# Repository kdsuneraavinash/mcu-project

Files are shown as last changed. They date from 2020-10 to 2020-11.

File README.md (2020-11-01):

# Environment Monitoring IoT Device with Common Alert Protocol

> A device developed using the NodeMCU ESP32S micro-controller, which monitors environment parameters such as temperature, humidity, barometric pres-sure, and ambient light level. 

For a more detailed report see [HERE](Report/report.pdf)

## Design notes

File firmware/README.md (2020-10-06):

# Microcontroller Module Project

> Developed using NODEMCU-ESP32S using PlatformIo.

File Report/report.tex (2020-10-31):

\documentclass[12pt,a4paper]{article}

\usepackage[left=1in,top=1in,right=1in,bottom=1in]{geometry}
\usepackage[T1]{fontenc}
\usepackage[utf8]{inputenc}
\usepackage{minted}

\usepackage{courier}
\usepackage{indentfirst}
\usepackage{graphicx}
\usepackage[hidelinks]{hyperref}
\usepackage{tikz}
\usepackage{array}
\usepackage{tabularx}
\usepackage{enumitem}
\usepackage[ruled,vlined]{algorithm2e}
\SetAlFnt{\footnotesize}

\newcommand{\tab}[1]{\hspace*{25pt}}

\def\sectionskip{\medskip}
\def\sectionlineskip{\medskip}
\urlstyle{same}

\title{Title of Document}
\author{K. D. Sunera Avinash Chandrasiri (170081L)}

\begin{document}

% ======================================
% Cover Page
% ======================================

\begin{titlepage}
    \begin{tikzpicture}[overlay,remember picture]
    \end{tikzpicture}

    {\hfill\scshape\Large Final Report \par}
    {\hfill\scshape CS3242 Micro-controllers and Applications\par}
    {\vspace{.5cm}}
    {\hrule}
    \vspace{2.5cm}
    {\hfill\huge\bfseries Environment Monitoring IoT Device\par}
    {\hfill\huge\bfseries with Common Alert Protocol\par}
    \vspace{1cm}
    {\hfill\large K. D. Sunera Avinash Chandrasiri\par}
    {\hfill\large 170081L\par}
    \vfill
    \hfill \today \par
\end{titlepage}

\newpage

% ======================================
% Table of Contents
% ======================================

\tableofcontents
\newpage

% ======================================
% Scope of the project
% ======================================

\section{Introduction}

\subsection{Scope}

This project is a device developed using the
\textbf{NodeMCU 32S} micro-controller, which monitors
environment parameters such as \textbf{temperature,
    humidity, barometric pressure, and ambient
    light level}. The used micro-controller will
operate with low-power and via a wi-fi connection.
Even though the wi-fi connection network
availability may be unreliable, firmware
for the microcontroller is designed in a way
so that network unreliability would not
entirely hinder the operation of the sensor. \par

The device will connect with a remote server via
an HTTP request. Here the microcontroller will
use \textbf{CAP(Common Alert Protocol)} to deliver the
relevant parameters. This "server sync" will
happen once every 15 minutes. In these situations,
the device will send the mean and the standard
deviation of the samples the device collected
within that 15 minutes.  If the network connection
fails for some reason, the device would still cache
the requests(up to a certain extent) and resend/replay
those messages once the network reconnects. \par

The backend implemented for the project is a simple
server based off of python. It uses \textbf{flask}
framework and sqlite database. It simply accepts alert
notifications sent by the device and displays them
in a tabular manner. \par

\subsection{Features}

Following are some of the features available in the device.
Node that following list also includes the features that were
expected from the project as well as some special features.
\setlist{nolistsep}
\begin{itemize}[noitemsep]
    \item Measuring temperature, humidity, barometric pressure, and ambient light level.
    \item Syncing with the server every 15 minutes.
    \item Use Common Alert Protocol 1.2 to deliver the messages.
    \item Replay messages that failed to deliver to the server due to network issues.
    \item In case of replaying past messages, timestamp is also sent after retreiveing it via NTP, so the server can correctly order the messages.
    \item Create a unique session identifier at the initialization of the device.
    \item Support multi-device connections. Because of the above unique identifier, we can connect multiple devices to the server.
\end{itemize}

\newpage

\section{Design}

% ======================================
% Diagram to explain high-level design
% ======================================

\subsection{High Level Design}

Following the high level system diagram is shown.
The system will mainly consist of two major parts; embedded device and the remote server.
The device will use a Wi-Fi connection to connect to the remote server.

\begin{figure}[h]
    \centering
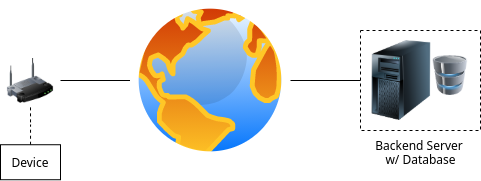
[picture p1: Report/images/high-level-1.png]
    
    \caption{High Level Deployment Diagram}
\end{figure}

The high-level diagram of the embedded device is shown below.
Here, the sensors required are connected; BMP180 (for pressure sensing),
DHT11 (for humidity and temperature sensing) and LDR(for light level sensing).

\begin{figure}[h]
    \centering
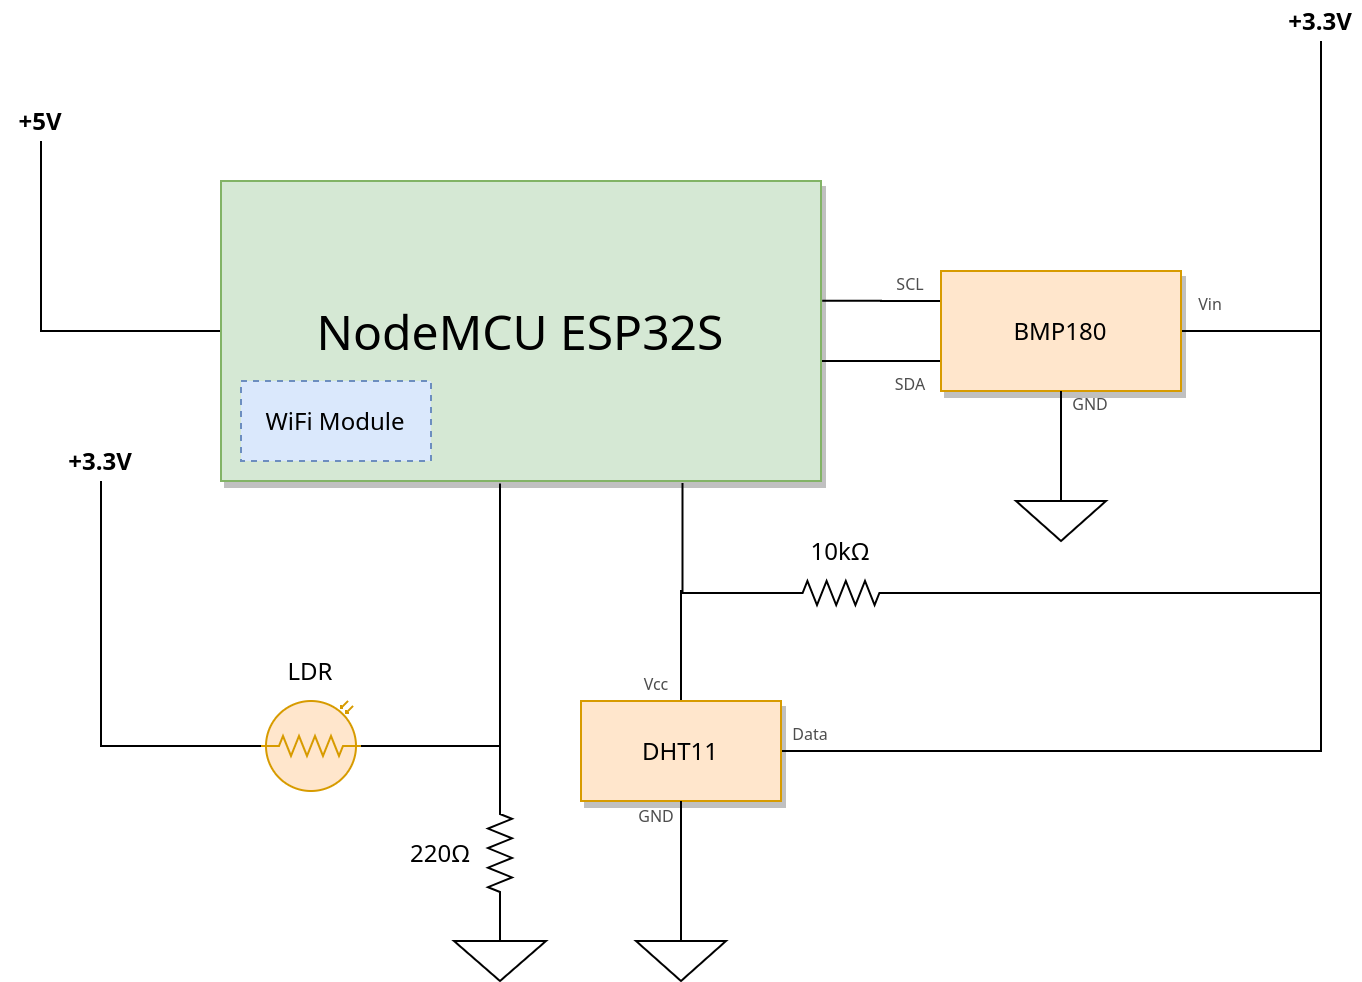
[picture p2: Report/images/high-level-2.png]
    
    \caption{High Level Device Diagram}
\end{figure}

\noindent The device will run on 5V input voltage while the input/output high
voltage of the NodeMCU will be 3.3V.

\clearpage

\newpage

% ======================================
%  List of components and their cost
% ======================================

\subsection{Components and Cost Breakdown}

\begin{figure}[!htb]
    \minipage{0.25\textwidth}
    \centering
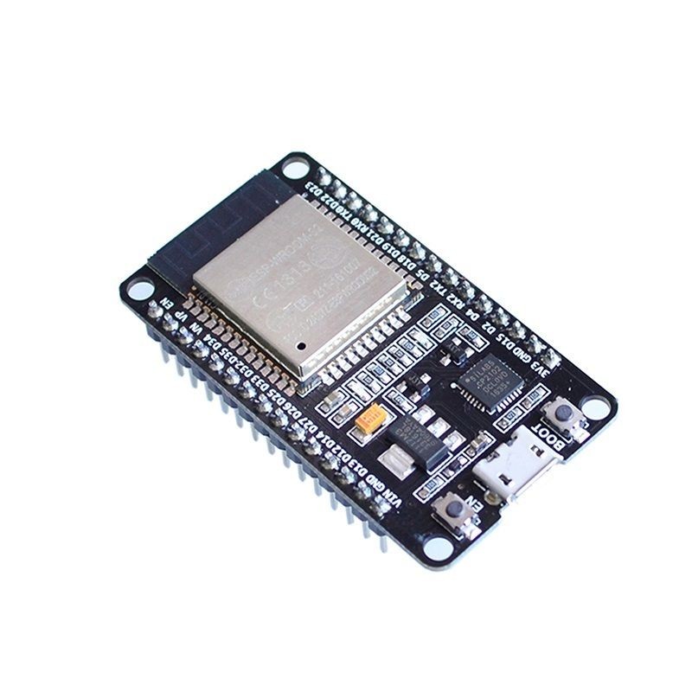
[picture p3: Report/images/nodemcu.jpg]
    
    \endminipage\hfill
    \minipage{0.25\textwidth}
    \centering
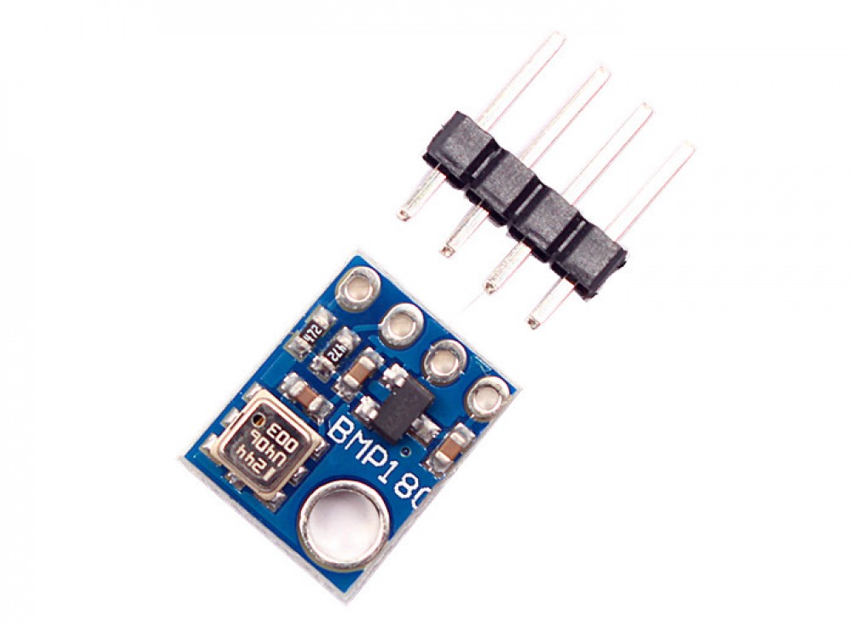
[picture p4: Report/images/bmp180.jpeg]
    
    \endminipage\hfill
    \minipage{0.25\textwidth}
    \centering
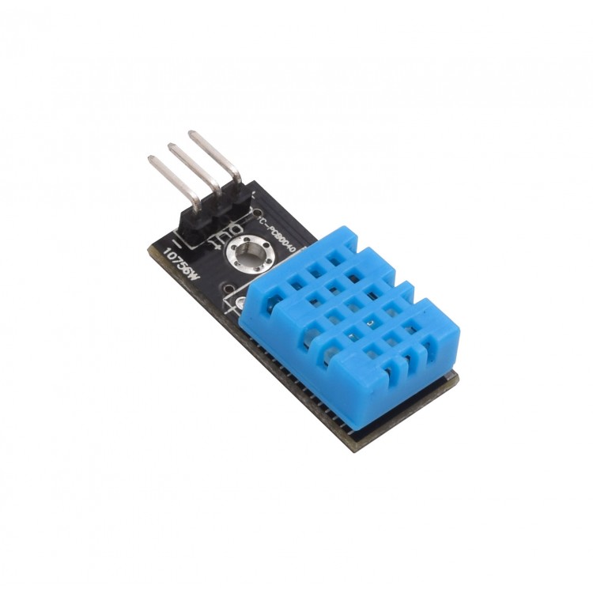
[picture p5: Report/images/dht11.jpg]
    
    \endminipage\hfill
    \minipage{0.25\textwidth}%
    \centering
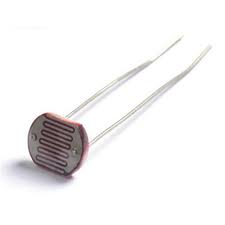
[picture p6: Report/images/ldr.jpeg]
    
    \endminipage
    \caption{From left to right - NodeMCU, BMP180, DHT11, LDR}
\end{figure}

The Price Breakdown for the product components are given below.
The chosen micro-controller board was \textbf{NodeMCU ESP-32S IoT Dev Board}
mainly because of its inbuilt Wi-Fi capabilities and its specialization
on such tasks, especially on IoT field.
Apart form that, for the sensors, following sensors were chosen. \par

\begin{figure}[h]
    \begin{tabular}{lp{11.5cm}}
        \textbf{DHT11 Sensor}  & Temperature and Relative Humidity Sensor Module. Temperature range is 0°C to 50°C (±1°C) and Humidity Range is 20\% to 90\% (±1\%) Operating voltage is  3.5V to 5.5V. \\
        \textbf{BMP180 Sensor} & Barometric Pressure sensor module. Range is 300hPa to 1100 hPa with 0.02 hPa accuracy. Operating voltage is 1.8-6 V.                                                   \\
        \textbf{LDR}           & Light Dependent Resistor for measuring ambient light level.                                                                                                            \\
    \end{tabular}
    \label{fig:layers}
\end{figure}

\noindent Cost breakdown for the device excluding connectors, resistors, bread-boards, etc... is given below.

\vspace{3mm}

\noindent\begin{tabularx}{\linewidth}{|X|r|}
    \hline
    \bf Component Name                                          & \bf Subtotal (LKR) \\
    \hline
    \hline
    NodeMCU ESP-32S WiFi Bluetooth Dual Mode IoT Dev Board      & 1050.00            \\
    BMP180 Barometric Pressure, Temperature and Altitude Sensor & 185.00             \\
    DHT11 Temperature and Relative Humidity Sensor Module       & 250.00             \\
    LDR 4mm                                                     & 10.00              \\
    \hline
    \hline
    \bf  Total Amount (LKR)                                     & \bf 1495.00        \\
    \hline
\end{tabularx}

\vspace{3mm}

The cost could have been further reduced by using a \textbf{NodeMCU ESP-8266} board.
This costs about half of the NodeMCU ESP-32S price.
However, ESP-32S was cited as being more reliable than ESP-8266.
So, ESP-32S was used.

\newpage

% ======================================
% Schematic diagram giving all components
% ======================================

\subsection{Schematic Diagram}

\vspace{2cm}

\begin{figure}[h]
    \centering
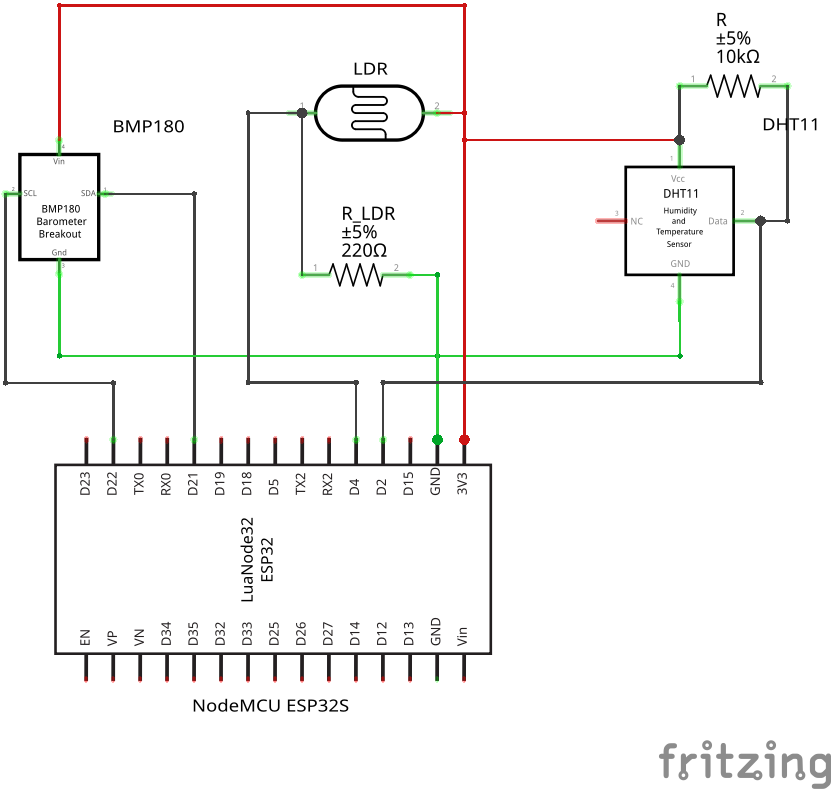
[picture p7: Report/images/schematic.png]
    
    \caption{Schematic Diagram of the device}
\end{figure}

\begin{figure}[H]
    \centering
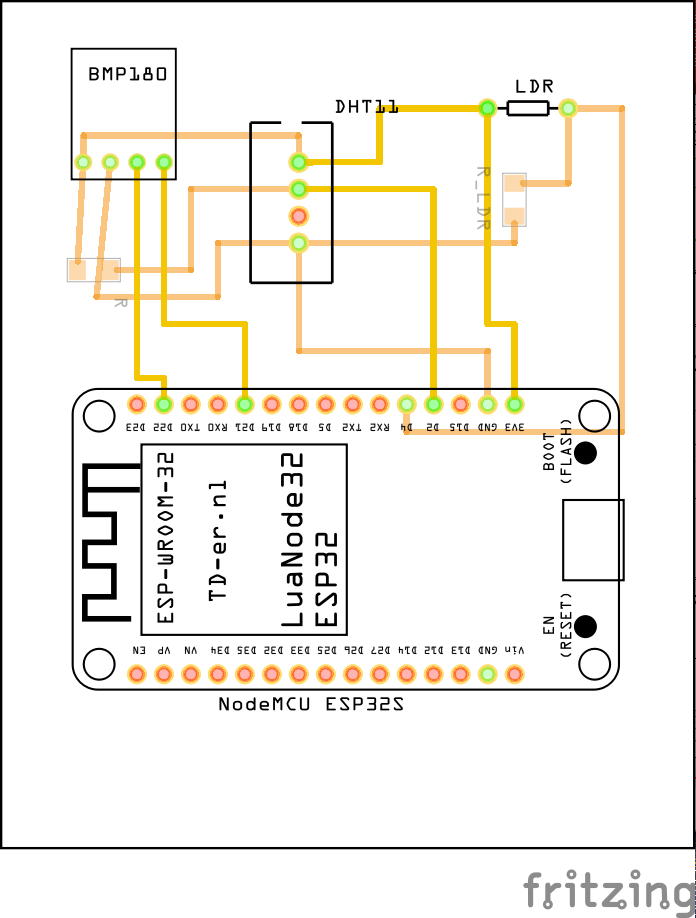
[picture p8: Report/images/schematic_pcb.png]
    
    \caption{Schematic PCB view of the prototype}
\end{figure}

\newpage

% ======================================
% Description on how fault recovery options areimplemented
% ======================================

\section{Implementation}

\subsection{Fault Recovery Implementation}

A simple queuing mechanism was used to mitigate the issue of unstable connectivity.
The firmware would first add the CAP records to the queue and then, when sending the data,
all the content in the queue will be sent.
In case some packet sending failed, (either because of no connectivity or server not being available)
the response from the server would fail or have an error status code.
In this case, that CAP record would again be added to the queue.
The queue would contain a bound so as to stop all the old records from being
on the memory and leading to a risk of memory overflow. Because of this bound, and
the implementation of the queue, once the connectivity continues, the most recent
records will be sent out to  the server.

Apart from queueing messages, the NodeMCU ESP32S contains an independently controlled
WiFi module which connects to the network even when it is disconnected. So, the module
will reconnect to the network in the case it was disconnected from the server due to
some reason.

\subsection{Prototype Implementation}

\begin{figure}[H]
    \centering
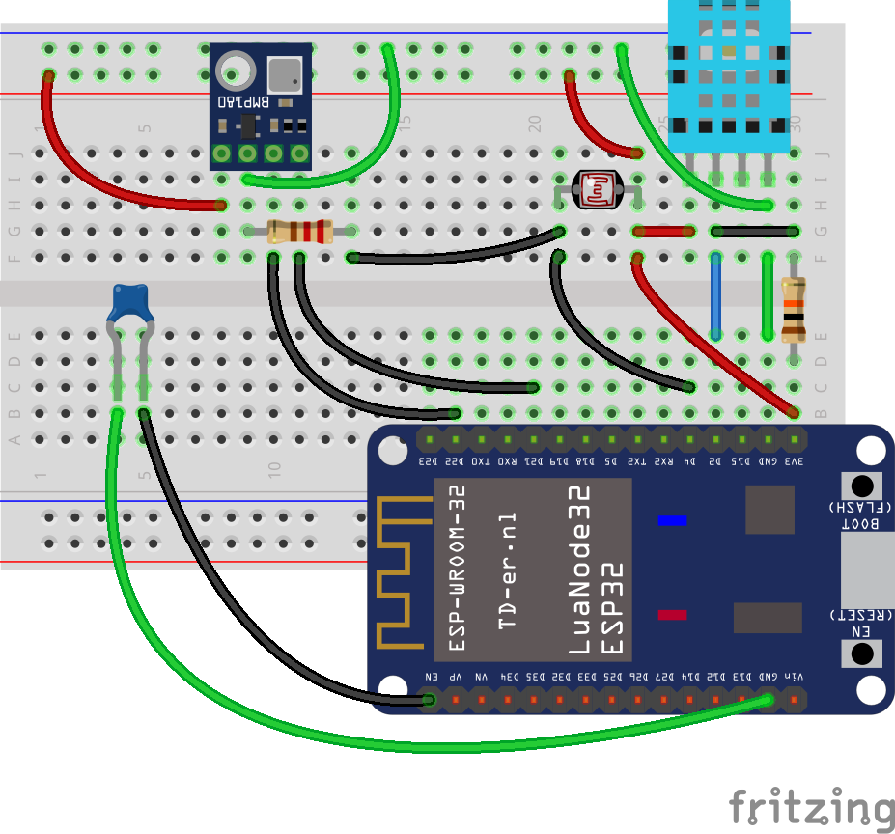
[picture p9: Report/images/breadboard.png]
    
    \caption{Prototype Implementation Design - Breadboard View}
\end{figure}

\begin{minipage}{0.45\linewidth}
    \begin{figure}[H]
        \centering
        
        \caption{Prototype Device}
    \end{figure}
\end{minipage}\hfil
\begin{minipage}{0.4\linewidth}
    As per the device implementation, I was able to connect the device as denoted in the
    above breadboard view and test it. However, due to some constraints  I was not able  to
    connect it to a dot-board or something similar.

    Furthermore, because of an issue with uploading to the microcontroller,
    I had to attach a capacitor to the EN pin. (Otherwise it would randomly fail)
\end{minipage}
\vspace{20pt}

As mentioned in the overview, the remote server part of the system was implemented using flask.
The database used for the prototype was a simple SQLite database.
Web interface of the prototype consisted of a simple table containing all the
sensor data that was received along with the timestamp that the data was recorded by the MCU.
Following is a screenshot of this web application dashboard.

\begin{figure}[H]
    \centering
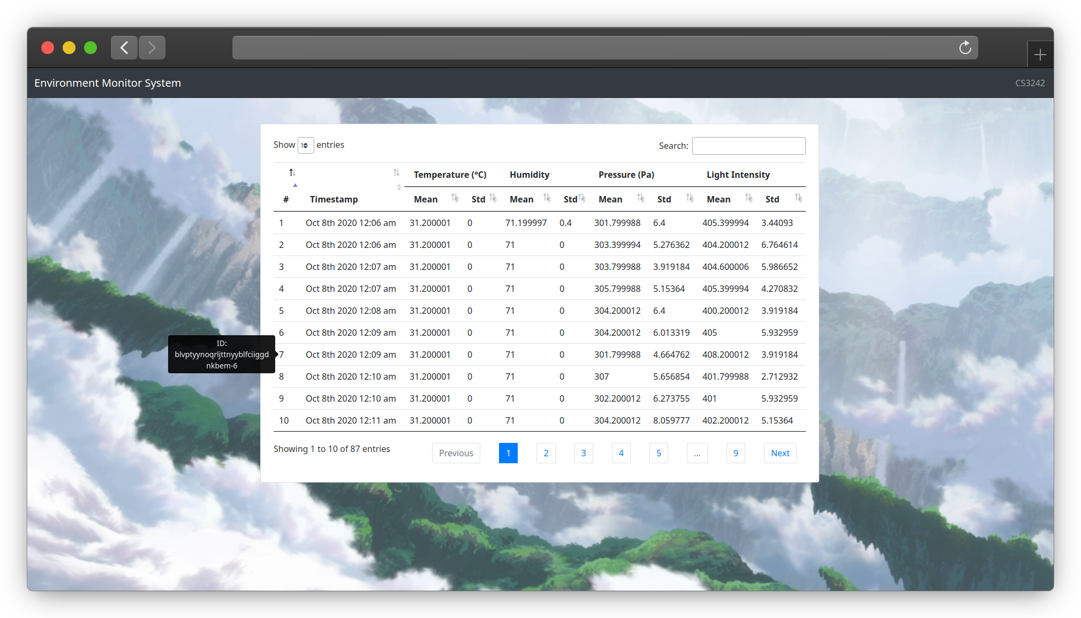
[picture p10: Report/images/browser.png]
    
    \caption{Prototype Dashboard Screenshot}
\end{figure}

For the CAP implementation, CAP on the device side was done manually. (without any explicit libraries dedicated for CAP)
However, some caveats were used to send the required fields in the CAP XML request.

For the \textbf{timestamp field}, a NTP library was used. This would fetch the current time from a remote server.
For the \textbf{identifier field}, the device would first generate a random string of 32 characters.
This will be seeded by the voltage of 0 pin. (This is floating, thus ensuring randomness)
This 32-character string will be used as the session identifier.
Each message sent in this session would be suffixed by an incrementing integer.
This ensures that 2 devices can operate with the same server without any interference.

\newpage

% ======================================
% Algorithm used for device and server (Pseudo code)
% ======================================

\subsection{Algorithm}

\begin{algorithm}[H]
    \SetAlgoLined
    \SetKwInOut{Input}{input}\SetKwInOut{Output}{output}
    \DontPrintSemicolon
    \SetKwProg{Fn}{Function}{ is}{end}

    $queue \longleftarrow LifoQueue()$\;
    $tempSamples \longleftarrow array()$\;
    $humiditySamples \longleftarrow array()$\;
    $pressureSamples \longleftarrow array()$\;
    $lightSamples \longleftarrow array()$\;
    $samplesCollected \longleftarrow 0$\;
    \BlankLine

    \Fn{sendSamples()}{
        \tcp*{find mean \& std}
        $tempMean \longleftarrow mean(tempSamples)$\;
        \tcp{$...$}
        $lightStd \longleftarrow std(tempSlightSamplesamples)$\;
        \BlankLine
        \tcp*{Add message to end of queue}
        $cap \longleftarrow createCapMessage(tempMean, ..., lightStd)$\;

        \If {$queue.isFull()$}{
            $queue.pop()$\;
        }
        $queue.push(cap)$\;

        \BlankLine
        \tcp*{send all current messages}
        $currentQueueSize \longleftarrow queue.size()$\;
        \For{$i\leftarrow 0$ \KwTo $currentQueueSize$}{
            $capEntry \longleftarrow queue.pop()$\;
            $response \longleftarrow wifi.sendPostRequest(capEntry)$\;
            \tcp*{Re-add failed requests}
            \If {$response = ERR \lor response.status \neq 200$}{
                $queue.push(capEntry)$\;
            }
        }

        \BlankLine
        \tcp*{reset variables}
        $samplesCollected \leftarrow 0$\;
        $tempSamples.clear()$\;
        \tcp{$...$}
        $lightSamples.clear()$\;
    }

    \BlankLine
    \Fn{collectSamples()}{
        $temp \leftarrow readDHT11()$\;
        $humidity \leftarrow readDHT11()$\;
        $pressure \leftarrow readBMP180()$\;
        $light \leftarrow readLDR()$\;
        $tempSamples.add(temp)$\;
        \tcp{$...$}
        $lightSamples.add(light)$\;
        $samplesCollected++$\;
    }

    \BlankLine
    \Begin{
        \While{$True$}{
            \If {$timeSinceLastRead() \geq \Delta$}{
                \lIf{$samplesCollected == N$}
                { $sendSamples()$ }
                { $collectSamples()$ }
            }
        }
    }
    \caption{Pseudo code of the firmware}\label{algo}
\end{algorithm}\DecMargin{1em}
\clearpage

\newpage

% ======================================
% Full Source Code
% ======================================

\section{Annexure}

\definecolor{beige}{rgb}{0.96, 0.96, 0.86}
\definecolor{azure}{rgb}{0.94, 1.0, 1.0}

\newcommand{\PythonCode}[1]{\inputminted
    [fontsize=\footnotesize,frame=lines,framerule=1pt,
        label=REMOTE\_SERVER\StrGobbleLeft{#1}{10},framesep=10pt]
    {python}{#1}}
\newcommand{\HtmlCode}[1]{\inputminted
    [fontsize=\footnotesize,frame=lines,framerule=1pt,
        label=REMOTE\_SERVER\StrGobbleLeft{#1}{10},framesep=10pt]
    {html}{#1}}
\newcommand{\SqlCode}[1]{\inputminted
    [fontsize=\footnotesize,frame=lines,framerule=1pt,
        label=schema.sql,framesep=10pt]
    {sql}{#1}}
\newcommand{\CppCode}[1]{\inputminted
    [fontsize=\footnotesize,frame=lines,framerule=1pt,
        label=FIRMWARE\StrGobbleLeft{#1}{11},framesep=10pt]
    {c++}{#1}}

\subsection{Firmware Source Code}

\CppCode{../firmware/src/main.cpp}
\newpage
\CppCode{../firmware/src/utils.h}
\CppCode{../firmware/src/utils.cpp}
\newpage

\CppCode{../firmware/src/cap/cap.h}
\CppCode{../firmware/src/cap/statistic.h}
\CppCode{../firmware/src/cap/cap.cpp}
\newpage

\CppCode{../firmware/src/sensor/dht.h}
\CppCode{../firmware/src/sensor/dht.cpp}
\newpage
\CppCode{../firmware/src/sensor/bmp180.h}
\CppCode{../firmware/src/sensor/bmp180.cpp}
\CppCode{../firmware/src/sensor/ldr.h}
\CppCode{../firmware/src/sensor/ldr.cpp}
\newpage
\CppCode{../firmware/src/sensor/sensor.h}
\CppCode{../firmware/src/sensor/sensor.cpp}
\newpage

\CppCode{../firmware/src/wifi/config.h}
\CppCode{../firmware/src/wifi/controller.h}
\CppCode{../firmware/src/wifi/ntp.h}
\newpage
\CppCode{../firmware/src/wifi/controller.cpp}
\CppCode{../firmware/src/wifi/ntp.cpp}
\newpage

\subsection{Remote Server Source Code}

\PythonCode{../backend/app.py}
\newpage
\PythonCode{../backend/db/entry.py}
\newpage
\PythonCode{../backend/db/database.py}
\newpage
\HtmlCode{../backend/templates/index.html}
\newpage

\subsection{Remote Server Database Schema}

\SqlCode{../backend/db/schema.sql}
\newpage

% ======================================
% References
% ======================================

% \begin{thebibliography}{9}

%     \bibitem{bib:fritzing}
%     \url{https://fritzing.org/} - Fritzing tool was used to design the schematic diagrams of the prototype.

% \end{thebibliography}

\end{document}

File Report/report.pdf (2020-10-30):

### Final Report

CS3242 Micro-controllers and Applications

# Environment Monitoring IoT Device with Common Alert Protocol

## K. D. Sunera Avinash Chandrasiri

170081L

## October 30, 2020

# Contents

1 Introduction | 2
2 Design | 3
3 Implementation | 7
4 Annexure | 9

# 1 Introduction

## 1.1 Scope

This project is a device developed using the NodeMCU 32S micro-controller, which monitors environment parameters such as temperature, humidity, barometric pressure, and ambient light level. The used micro-controller will operate with low-power and via a wi-fi connection. Even though the wi-fi connection network availability may be unreliable, firmware for the microcontroller is designed in a way so that network unreli-

ability would not entirely hinder the operation of the sensor.

## The device will connect with a remote server via an HTTP request. Here the micro-

controller will use CAP(Common Alert Protocol) to deliver the relevant parameters. This "server sync" will happen once every 15 minutes. In these situations, the device will

## send the mean and the standard deviation of the samples the device collected within that 15 minutes. If the network connection fails for some reason, the device would still cache the requests(up to a certain extent) and resend/replay those messages once the network

reconnects.

## The backend implemented for the project is a simple server based off of python. It uses flask framework and sqlite database. It simply accepts alert notifications sent by

the device and displays them in a tabular manner.

## 1.2 Features

## Following are some of the features available in the device. Node that following list also includes the features that were expected from the project as well as some special

features.
- Measuring temperature, humidity, barometric pressure, and ambient light level.
- Syncing with the server every 15 minutes.
- Use Common Alert Protocol 1.2 to deliver the messages.
- Replay messages that failed to deliver to the server due to network issues.

## - In case of replaying past messages, timestamp is also sent after retreiveing it via

NTP, so the server can correctly order the messages.
- Create a unique session identifier at the initialization of the device.

## - Support multi-device connections. Because of the above unique identifier, we can

connect multiple devices to the server.

# 2 Design

## 2.1 High Level Design

## Following the high level system diagram is shown. The system will mainly consist of two major parts; embedded device and the remote server. The device will use a Wi-Fi

connection to connect to the remote server.

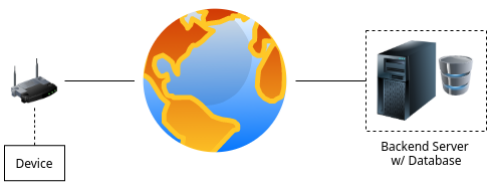
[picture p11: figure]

## Figure 1: High Level Deployment Diagram

## The high-level diagram of the embedded device is shown below. Here, the sensors required are connected; BMP180 (for pressure sensing), DHT11 (for humidity and tem-

perature sensing) and LDR(for light level sensing).

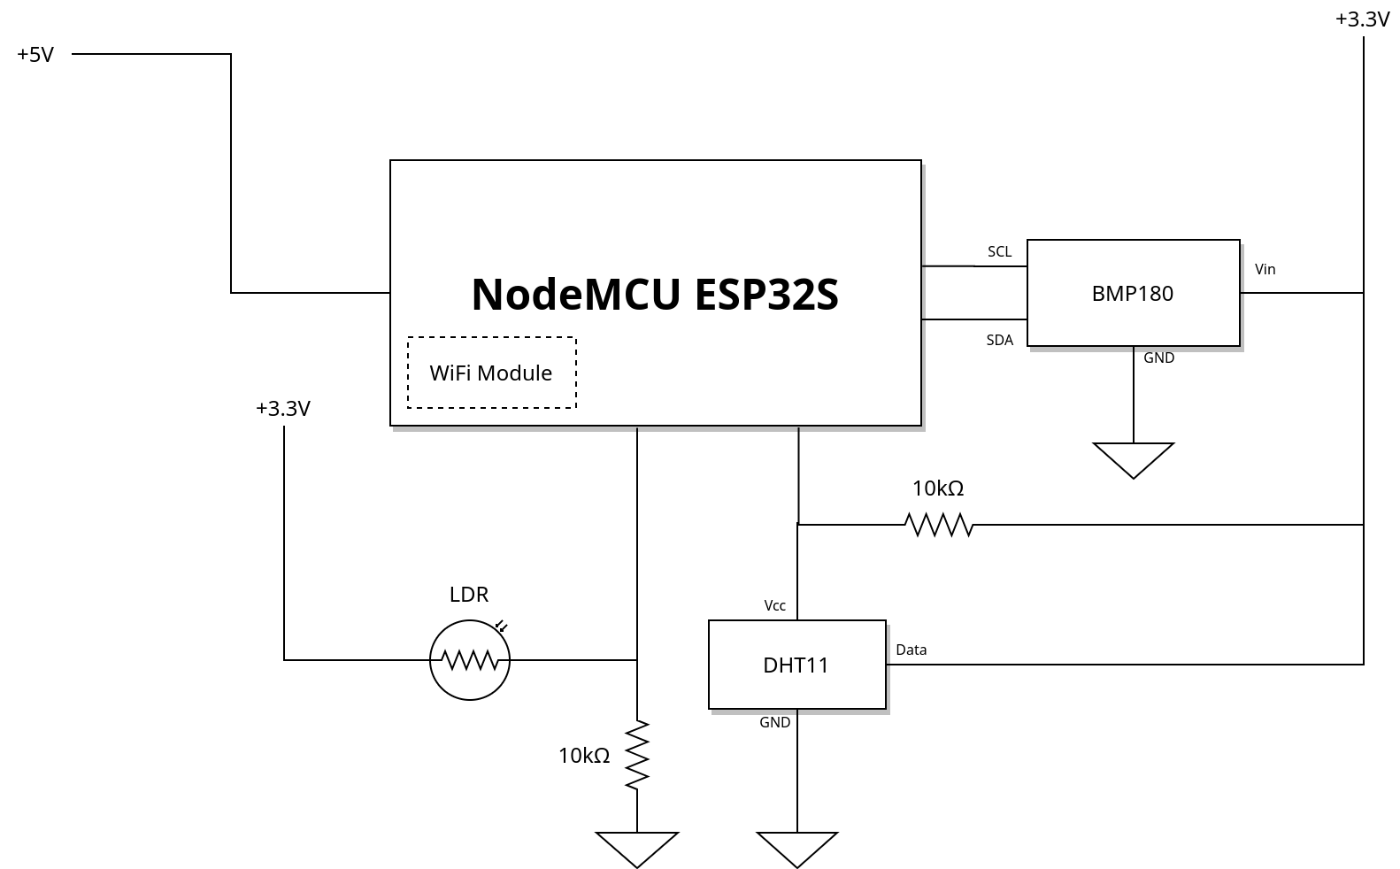
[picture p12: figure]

## Figure 2: High Level Device Diagram

## The device will run on 5V input voltage while the input/output high voltage of the

NodeMCU will be 3.3V.

## 2.2 Components and Cost Breakdown


## Figure 3: From left to right - NodeMCU, BMP180, DHT11, LDR

## The Price Breakdown for the product components are given below. The chosen microcontroller board was NodeMCU ESP-32S IoT Dev Board mainly because of its

inbuilt Wi-Fi capabilities and its specialization on such tasks, especially on IoT field. Apart form that, for the sensors, following sensors were chosen.

DHT11 Sensor | Temperature and Relative Humidity Sensor Module. Tempera- ture range is 0°C to 50°C (±1°C) and Humidity Range is 20% to
| 90% (±1%) Operating voltage is 3.5V to 5.5V.

## BMP180 Sensor Barometric Pressure sensor module. Range is 300hPa to 1100

| hPa with 0.02 hPa accuracy. Operating voltage is 1.8-6 V.
LDR | Light Dependent Resistor for measuring ambient light level.

Cost breakdown for the device excluding connectors, vero-boards, etc... is given below.

Component Name | Subtotal (LKR)
NodeMCU ESP-32S WiFi Bluetooth Dual Mode IoT Dev Board BMP180 Barometric Pressure, Temperature and Altitude Sensor DHT11 Temperature and Relative Humidity Sensor Module LDR 4mm | 1050.00 185.00 250.00 10.00
Total Amount (LKR) | 1495.00

The cost could have been further reduced by using a NodeMCU ESP-8266 board.

## This costs about half of the NodeMCU ESP-32S price. However, ESP-32S was cited as

being more reliable than ESP-8266. So, ESP-32S was used.

## 2.3 Schematic Diagram

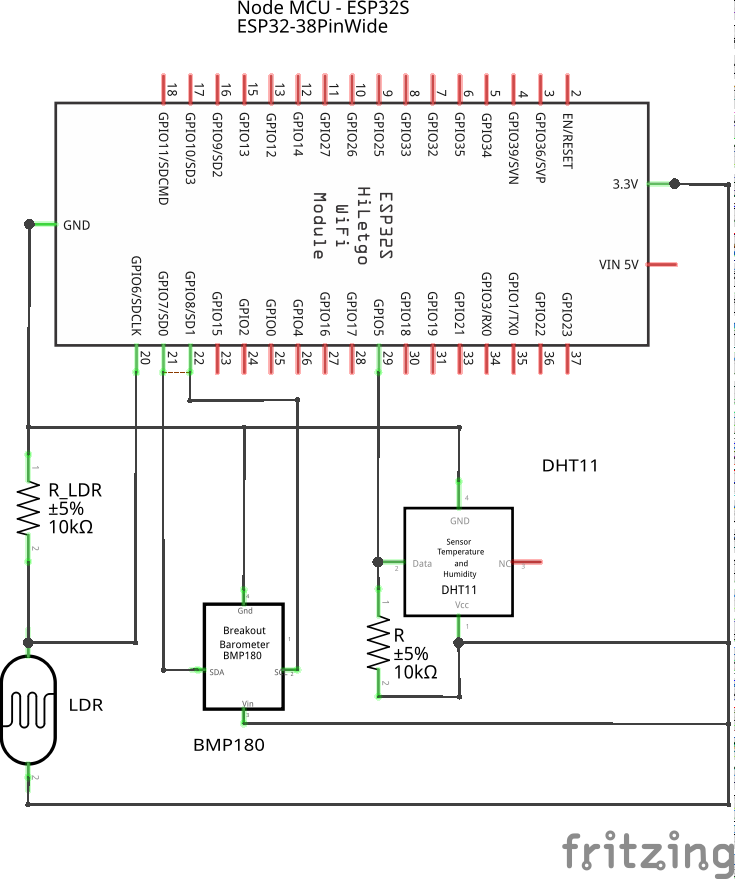
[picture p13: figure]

## Figure 4: Schematic Diagram of the device

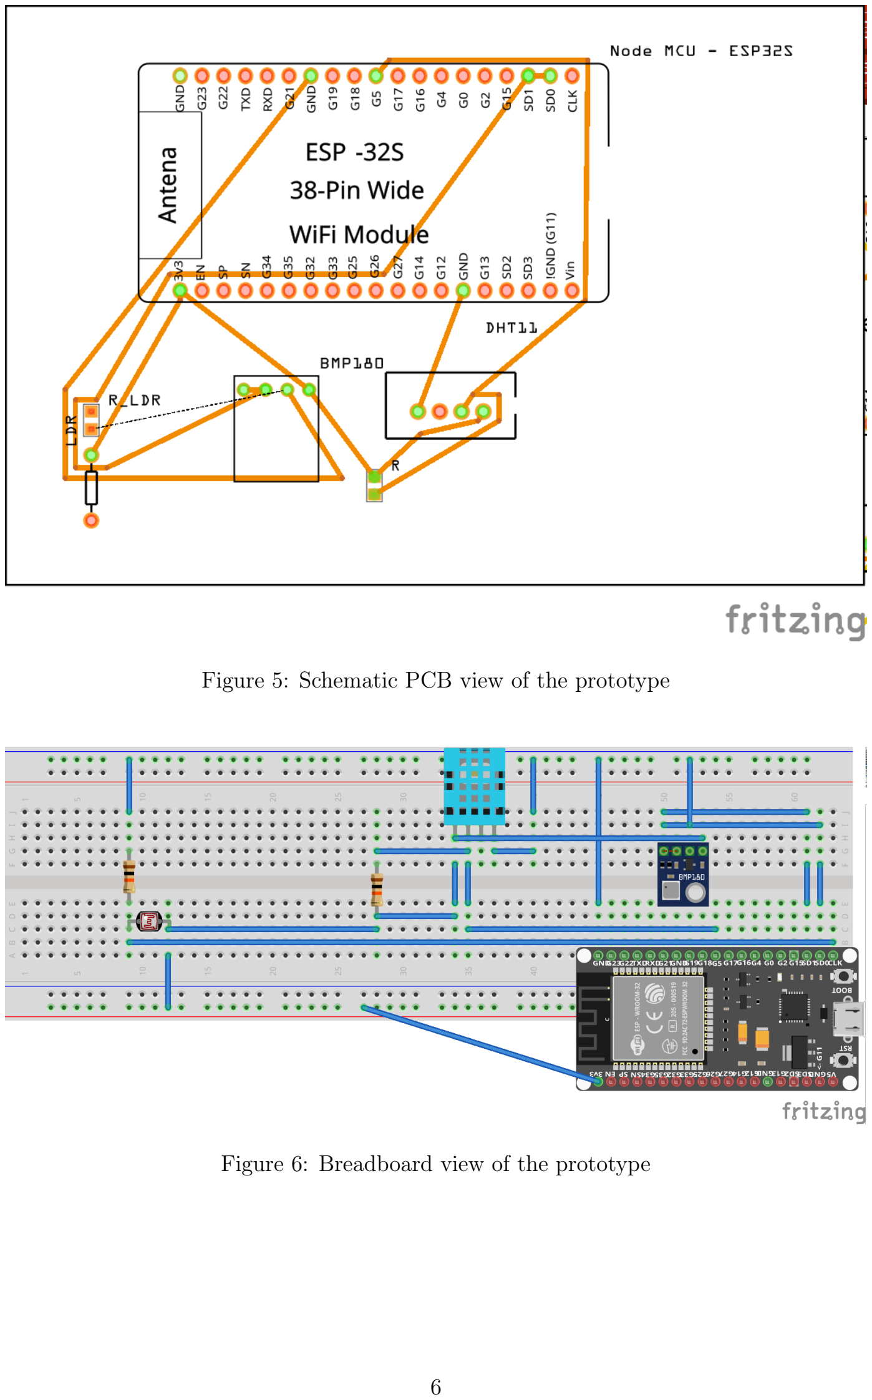
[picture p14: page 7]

## Figure 5: Schematic PCB view of the prototype

## Figure 6: Breadboard view of the prototype

# 3 Implementation

## 3.1 Fault Recovery Implementation

## 3.2 Algorithm

## Algorithm 1: Pseudo code of the algorithm implemented

### queue ←− LifoQueue() tempSamples ←− array() humiditySamples ←− array() pressureSamples ←− array() lightSamples ←− array() samplesCollected ←− 0

### Function sendSamples() is

// find mean & std

### tempMean ←− mean(tempSamples)

// ...

### lightStd ←− std(tempSlightSamplesamples)

// Add message to end of queue

### cap ←− createCapMessage(tempMean, ..., lightStd) if queue.isF ull() then queue.pop() end queue.push(cap)

// send all current messages

### currentQueueSize ←− queue.size() for i ← 0 to currentQueueSize do capEntry ←− queue.pop() response ←− wif i.sendP ostRequest(capEntry)

// Re-add failed requests

### if response = ERR ∨ response.status 6= 200 then queue.push(capEntry) end end

// reset variables

### samplesCollected ← 0 tempSamples.clear()

// ...

### lightSamples.clear() end

### Function collectSamples() is temp ← readDHT11() humidity ← readDHT11() pressure ← readBMP180() light ← readLDR() tempSamples.add(temp)

// ...

### lightSamples.add(light) samplesCollected + + end

### begin while T rue do if timeSinceLastRead() ≥ ∆ then if samplesCollected == N then sendSamples() collectSamples() end end end

# 4 Annexure

## 4.1 Server Source Code

REMOTE_SERVER/app.py

from flask import Flask
from flask import request
from capparselib.parsers import CAPParser from flask import render_template

from db import database, entry

app = Flask(__name__)
database.init_app(app)

@app.route('/', methods=["POST"])
def get_update():
alerts = CAPParser(request.data.decode('utf-8')).as_dict() alert = alerts[0]
params = {}
for param in alert['cap_info'][0]['cap_parameter']:
name = param['valueName']
value = param['value']
params[name] = value
entry.save_entry(alert, params) return "200 - ACK"

@app.route('/', methods=["GET"])
def view():
entries = entry.get_all_entries()
return render_template('index.html', entries=entries)

if __name__ == '__main__':
app.run()

REMOTE_SERVER/db/entry.py

from db.database import get_db from datetime import datetime

def get_all_entries():
c = get_db().cursor()
c.execute("""
select identifier, CAST(sent as TEXT) as sent, info_parameter_temp_mean, info_parameter_temp_std, info_parameter_humidity_mean, info_parameter_humidity_std, info_parameter_pressure_mean, info_parameter_pressure_std, info_parameter_light_mean, info_parameter_light_std
from entry order by sent;
""")
return c.fetchall()

def save_entry(cap, params): conn = get_db()
c = conn.cursor()
c.execute("""
INSERT INTO entry (identifier, sender, sent, status, msgType, scope, info_category, info_event, info_responseType,
info_urgency, info_severity, info_certainty, info_senderName, info_parameter_temp_mean, info_parameter_temp_std, info_parameter_humidity_mean, info_parameter_humidity_std, info_parameter_pressure_mean, info_parameter_pressure_std, info_parameter_light_mean, info_parameter_light_std) VALUES (?, ?, ?, ?, ?, ?, ?, ?, ?, ?, ?, ?, ?, ?, ?, ?, ?, ?, ?, ?, ?); """,
(
str(cap['cap_id']),
str(cap['cap_sender']),
datetime.fromisoformat(str(cap['cap_sent'])), str(cap['cap_status']),
str(cap['cap_message_type']), str(cap['cap_scope']),
str(cap['cap_info'][0]['cap_category']), str(cap['cap_info'][0]['cap_event']), str(cap['cap_info'][0]['cap_response_type']), str(cap['cap_info'][0]['cap_urgency']), str(cap['cap_info'][0]['cap_severity']), str(cap['cap_info'][0]['cap_certainty']), str(cap['cap_info'][0]['cap_sender_name']), float(params['TEMP_MEAN']), float(params['TEMP_STD']), float(params['HUMIDITY_MEAN']), float(params['HUMIDITY_STD']), float(params['PRESSURE_MEAN']), float(params['PRESSURE_STD']), float(params['LIGHT_MEAN']), float(params['LIGHT_STD']),
))
conn.commit()

REMOTE_SERVER/db/database.py

import sqlite3

import click
from flask import current_app, g from flask.cli import with_appcontext

def init_db():
db = get_db()
with current_app.open_resource('schema.sql') as f: db.executescript(f.read().decode('utf8'))

@click.command('init-db')
@with_appcontext
def init_db_command():
"""Clear the existing data and create new tables.""" init_db()
click.echo('Initialized the database.')

def init_app(app):
app.teardown_appcontext(close_db) app.cli.add_command(init_db_command)

def get_db():
if 'db' not in g:
g.db = sqlite3.connect(
'db/database.db',
detect_types=sqlite3.PARSE_DECLTYPES )
g.db.row_factory = sqlite3.Row

return g.db

def close_db(e=None):
db = g.pop('db', None)
if db is not None:
db.close()

## 4.2 Device Source Code

FIRMWARE/src/main.cpp

#include <Arduino.h>

#include <cppQueue.h>

#include "cap/cap.h"

#include "sensor/bmp180.h" #include "sensor/dht.h"

#include "sensor/sensor.h" #include "utils.h"

#include "wifi/controller.h" #include "wifi/ntp.h"

#define CAP_SIZE 3000

#define N_SAMPLES 5

#define CACHE_SIZE 10

#define REMOTE_SERVER "http://7e86ccb1d82f.ngrok.io/"

#define SYNC_PERIOD (30 * 1000)

#define SAMPLE_PERIOD (SYNC_PERIOD / (N_SAMPLES))

float tempSamples[N_SAMPLES];
float humiditySamples[N_SAMPLES];
float pressureSamples[N_SAMPLES]; float lightSamples[N_SAMPLES];
int currentSample = 0;
unsigned long lastSampleMillis; Queue capQueue(CAP_SIZE, CACHE_SIZE);

void clearSample(float* buffer) {
for (int i = 0; i < N_SAMPLES; i++) { buffer[i] = NULL;
}
}

void clearSamples() {
clearSample(tempSamples);
clearSample(humiditySamples); clearSample(pressureSamples); clearSample(lightSamples);
}

statistic toStatistic(float* buffer) {
float sensorMean = mean(buffer, N_SAMPLES);
float sensorStd = standardDeviation(buffer, N_SAMPLES, sensorMean); return {sensorMean, sensorStd};
}

void setup() {
pinMode(LED_BUILTIN, OUTPUT); Serial.begin(115200);
initializeConnection();
initializeNtp();
setupIdentifier();
initializeDHT();
initializeBMP();
clearSamples();

}

void loop() {
if (millis() - lastSampleMillis < SAMPLE_PERIOD) { return;
}

lastSampleMillis = millis();
if (currentSample == N_SAMPLES) { Serial.println("[MAIN] Starting server sync..."); char cap[CAP_SIZE];
statistic temp = toStatistic(tempSamples); statistic humidity = toStatistic(humiditySamples); statistic pressure = toStatistic(pressureSamples); statistic light = toStatistic(lightSamples);
generateCap(cap, CAP_SIZE, temp, humidity, pressure, light);
if (capQueue.isFull()) {
Serial.println("[CACHE] CAP cache full, discarding oldest entry."); capQueue.drop();
}
capQueue.push(cap);
char serverAddress[] = REMOTE_SERVER; processCapQueue(&capQueue, CAP_SIZE, serverAddress); currentSample = 0;
clearSamples();
} else {
Serial.println("[MAIN] Starting sensor sync..."); float temp = sampleTemperature();
float humidity = sampleHumidity();
float pressure = samplePressure();
float light = sampleLight(); tempSamples[currentSample] = temp; humiditySamples[currentSample] = humidity; pressureSamples[currentSample] = pressure; lightSamples[currentSample] = light; currentSample++;
}
}

FIRMWARE/src/utils.h

#ifndef UTILS_H

#define UTILS_H

float mean(float* buffer, int size);
float standardDeviation(float* buffer, int size, float mean);

#endif

FIRMWARE/src/utils.cpp

#include <math.h>

float mean(float* buffer, int size) { float sum = 0.0;
int count = 0;
for (int i = 0; i < size; i++) { if (buffer[i] >= 0) {
count++;
sum += buffer[i];
}
}
if (count == -1) return -1; return sum / count;
}

float standardDeviation(float* buffer, int size, float mean) { float std = 0.0;
int count = 0;
for (int i = 0; i < size; i++) {
if (buffer[i] >= 0) {
count++;
std += pow(buffer[i] - mean, 2); }
}
if (count == -1) return -1;
return pow(std / count, 0.5); }

FIRMWARE/src/cap/cap.h

#ifndef CAP_H

#define CAP_H

#include "statistic.h"

void generateCap(char* buffer, int buffer_size, statistic temp, statistic humidity, statistic pressure, statistic light); void setupIdentifier();

#endif

FIRMWARE/src/cap/statistic.h

#ifndef STATISTIC_H

#define STATISTIC_H

struct statistic {
float mean;
float std;
};

#endif

FIRMWARE/src/cap/cap.cpp

#include <Arduino.h>

#include <esp_system.h>

#include <stdio.h>

#include "../wifi/ntp.h"

#include "statistic.h"

#define IDENTIFIER_LENGTH 32

const char* CAP_TEMPLATE =
"<?xml version = \"1.0\" encoding = \"UTF-8\"?>"
"<alert xmlns = \"urn:oasis:names:tc:emergency:cap:1.2\">"
" | <identifier>%s-%d</identifier>"
" | <sender>MCU_DEVICE</sender>"
" | <sent>%s</sent>"
" | <status>Actual</status>"
" | <msgType>Alert</msgType>"
" | <scope>Private</scope>"
" | <info>"
" | <category>Env</category>"
" | <event>SENSOR_DATA</event>"
" | <responseType>None</responseType> "
" | <urgency>Unknown</urgency>"
" | <severity>Minor</severity>"
" | <certainty>Observed</certainty>"
" | <senderName>mcu_session_%s</senderName>"
" | <parameter>"
" | <valueName>TEMP_MEAN</valueName>"
" | <value>%f</value>"
" | </parameter>"
" | <parameter>"

" | <valueName>TEMP_STD</valueName>"
" | <value>%f</value>"
" | </parameter>"
" | <parameter>"
" | <valueName>HUMIDITY_MEAN</valueName>"
" | <value>%f</value>"
" | </parameter>"
" | <parameter>"
" | <valueName>HUMIDITY_STD</valueName>"
" | <value>%f</value>"
" | </parameter>"
" | <parameter>"
" | <valueName>PRESSURE_MEAN</valueName>"
" | <value>%f</value>"
" | </parameter>"
" | <parameter>"
" | <valueName>PRESSURE_STD</valueName>"
" | <value>%f</value>"
" | </parameter>"
" | <parameter>"
" | <valueName>LIGHT_MEAN</valueName>"
" | <value>%f</value>"
" | </parameter>"
" | <parameter>"
" | <valueName>LIGHT_STD</valueName>"
" | <value>%f</value>"
" | </parameter>"
" | </info>"
"</alert>";

int currentIdentifier = 0;
char randomIdentifier[IDENTIFIER_LENGTH + 1];

void setupIdentifier() {
randomSeed(analogRead(0));
for (int i = 0; i < IDENTIFIER_LENGTH; i++) { byte randomValue = random(0, 26);
randomIdentifier[i] = randomValue + 'a';
}
Serial.printf("[CAP] Identifier: %s\n", randomIdentifier); }

void generateCap(char* buffer, int buffer_size, statistic temp,
| statistic humidity, statistic pressure, statistic light) {
updateTime();

Serial.println("[CAP] Compiling protocol XML."); snprintf(buffer, buffer_size, CAP_TEMPLATE, randomIdentifier,
| currentIdentifier++, formattedDate, randomIdentifier, temp.mean,
| temp.std, humidity.mean, humidity.std, pressure.mean, pressure.std,
| light.mean, light.std);
}

FIRMWARE/src/sensor/bmp180.h

#ifndef BMP180_H

#define BMP180_H

void initializeBMP();
float readPressure();

#endif

FIRMWARE/src/sensor/dht.h

#ifndef DHT_H

#define DHT_H

void initializeDHT();
float readHumidity();
float readTemperature();

#endif

FIRMWARE/src/sensor/sensor.h

#ifndef SENSOR_H

#define SENSOR_H

float sampleTemperature(); float sampleHumidity();
float samplePressure();
float sampleLight();

#endif

FIRMWARE/src/sensor/bmp180.cpp

#include <Adafruit_BMP085.h> #include <Wire.h>

Adafruit_BMP085 bmp;

void initializeBMP() {
if (!bmp.begin()) {
Serial.println("[BMP] Could not find a valid BMP180 sensor."); }
}

float readPressure() {
if (!bmp.begin()) {
Serial.println("[DHT] Failed to read pressure from BMP sensor."); return -1;
}

float pressure = bmp.readPressure(); Serial.printf("[BMP] Pressure read: %f\n", pressure); return pressure;
}

FIRMWARE/src/sensor/dht.cpp

#include <Adafruit_Sensor.h> #include <Arduino.h>

#include <DHT.h>

#define DHTPIN 4

#define DHTTYPE DHT11

DHT dht(DHTPIN, DHTTYPE);

void initializeDHT() { dht.begin(); }

float readHumidity() {
float humidity = dht.readHumidity();
if (isnan(humidity)) {
Serial.println("[DHT] Failed to read humidity from DHT sensor."); return -1;
}

Serial.printf("[DHT] Humidity read: %f\n", humidity); return humidity;
}

float readTemperature() {
float temperature = dht.readTemperature();
if (isnan(temperature)) {
Serial.println("[DHT] Failed to read temperature from DHT sensor."); return -1;
}

Serial.printf("[DHT] Temperature read: %f\n", temperature); return temperature;
}

FIRMWARE/src/sensor/sensor.cpp

#include <Arduino.h>

#include "bmp180.h"

#include "dht.h"

float sampleTemperature() { return readTemperature(); }

float sampleHumidity() { return readHumidity(); }

float samplePressure() { return readPressure(); }

float sampleLight() { return 400 + (random(10) * 2 - 5); }

FIRMWARE/src/wifi/config.h

#ifndef WIFI_CONFIG_H

#define WIFI_CONFIG_H

extern const char* SSID;
extern const char* PASSWORD;

#endif

FIRMWARE/src/wifi/controller.h

#ifndef CONFIG_H

#define CONFIG_H

#include <cppQueue.h>

#include "config.h"

void initializeConnection();
bool sendPostRequest(char* message, char* endpoint);
void processCapQueue(Queue* capCache, int capSize, char* endpoint);

#endif

FIRMWARE/src/wifi/ntp.h

#ifndef NTP_H

#define NTP_H

#include <WString.h>

extern String formattedDate; extern String dayStamp;
extern String timeStamp;

void initializeNtp();
void updateTime();

#endif

FIRMWARE/src/wifi/controller.cpp

#include "controller.h"

#include <HTTPClient.h>

#include <WiFi.h>

#include <cppQueue.h>

#include "../cap/cap.h"

/**
* Initializing wifi connection.
* Configuring wifi module and connecting to the network. * */
void initializeConnection() {
WiFi.begin(SSID, PASSWORD);
Serial.print("[WIFI] Trying to connect..."); delay(1000);
while (WiFi.status() != WL_CONNECTED) { delay(500);
Serial.print(".");
}
const char* ip = WiFi.localIP().toString().c_str(); Serial.printf("\n[WIFI] Connected to network with IP: %s\n", ip); }

/**
* Sending the message body given to the endpoint * as a POST request.
* Will return false if attempt failed.
* */
bool sendPostRequest(char* message, char* endpoint) { if (WiFi.status() != WL_CONNECTED) { Serial.println("[WIFI] Not connected to a network."); return false;
}

// Send POST request
Serial.println("[WIFI] Sending POST request to the server..."); HTTPClient http;
http.begin(endpoint);
int responseCode = http.POST(message);
String response = http.getString(); http.end();

// Connection failed error codes
if (responseCode < 0) {
String errorMessage = http.errorToString(responseCode).c_str(); Serial.printf("[WIFI] Request failed: %s\n", errorMessage.c_str()); return false;
}

// Server returned error code
if (responseCode != HTTP_CODE_OK) {
Serial.printf("[WIFI] Server %d Response: %s\n", responseCode, response.c_str());
return false;
}

// Success
Serial.println("[WIFI] Data sent to the server."); return true;
}

void processCapQueue(Queue* capCache, int capSize, char* endpoint) { int queueLength = capCache->getCount();
for (int i = 0; i < queueLength; i++) {
Serial.printf("[CACHE] retrieved oldest CAP. %d remaining.\n", queueLength - i - 1);
char cap[capSize];
capCache->pop(cap);
bool success = sendPostRequest(cap, endpoint);
if (!success) {
Serial.println("[CACHE] Request failed. Readding to cache."); capCache->push(cap);
}
}
}

FIRMWARE/src/wifi/ntp.cpp

#include <NTPClient.h>

#include <WiFiUdp.h>

#define TIME_ZONE ((11 * 3600) / 2) #define TIMESTAMP_SIZE 50

WiFiUDP ntpUDP;
NTPClient timeClient(ntpUDP);

char formattedDate[50];

/**
* Initialize NTP connection.
* The WiFi must ve set-up at this point.
* */
void initializeNtp() {
Serial.println("[NTP] Starting NTP connection..."); timeClient.begin();
timeClient.setTimeOffset(TIME_ZONE);
Serial.printf("[NTP] NTP connected in %d time zone.\n", TIME_ZONE); }

/**
* Update NTP time and set global variables
* */
void updateTime() {
Serial.println("[NTP] Retrieving timestamp via ntp..."); while (!timeClient.update()) { timeClient.forceUpdate();
}
String date = timeClient.getFormattedDate();
date.replace("Z", "+05:30");
date.toCharArray(formattedDate, TIMESTAMP_SIZE); Serial.printf("[NTP] Retrieved timestamp: %s\n", formattedDate); }

# References

[1] https://fritzing.org/ - Fritzing tool was used to design the schematic diagrams of the prototype.

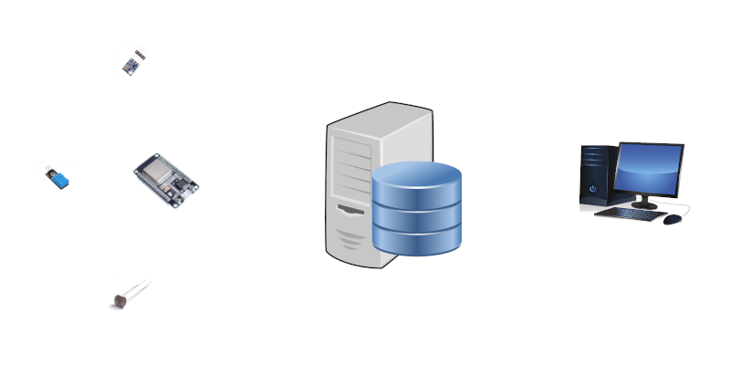
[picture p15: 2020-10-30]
Report/images/scope.png

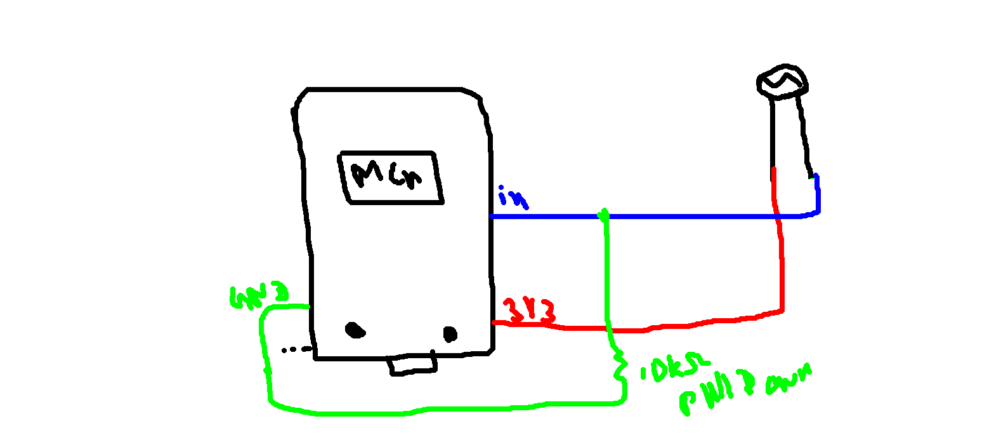
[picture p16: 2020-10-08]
ldr.png

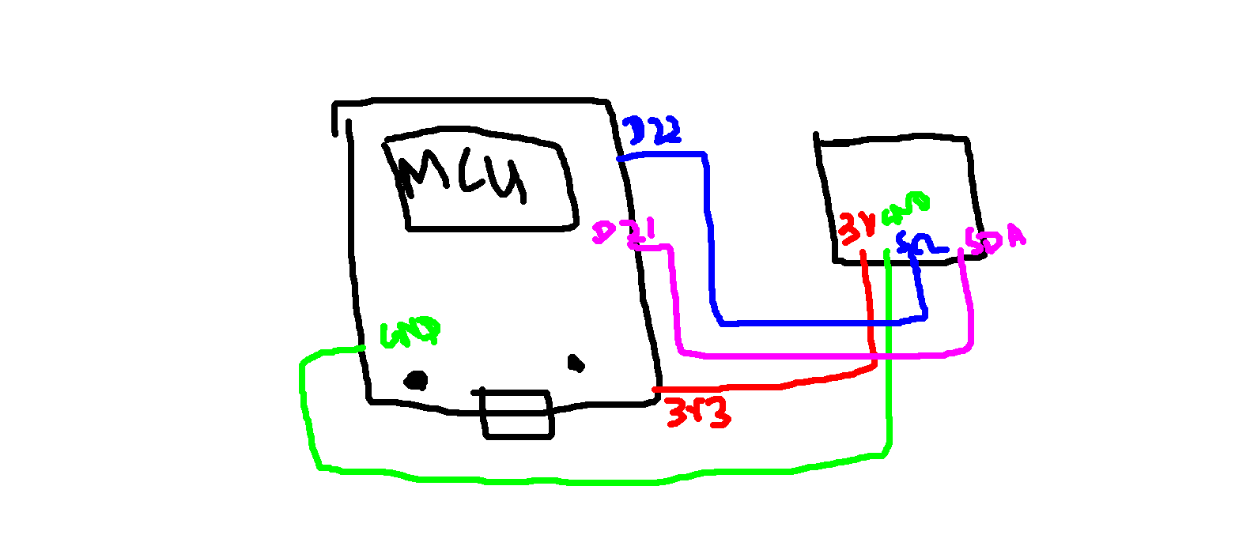
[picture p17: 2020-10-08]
bmp.png

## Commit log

2020-10-07 Added ESP32 code for dht sensor
2020-10-08 Attached BMP sensor
2020-10-30 Added partial report and some files
    [schematic.fzz]
2020-10-30 Added all required parts for the report
    [schematic.fzz, schematic_new.fzz]
